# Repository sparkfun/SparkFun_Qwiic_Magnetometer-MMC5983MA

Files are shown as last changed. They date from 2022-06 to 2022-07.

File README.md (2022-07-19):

# SparkFun_Qwiic_Magnetometer-MMC5983MA
========================================

SparkFun Qwiic Magnetometer-MMC5983MA (https://www.sparkfun.com/products/19921)

[*SparkFun Qwiic Magnetometer-MMC5983MA (19921)*](https://www.sparkfun.com/products/19921)

The SparkFun Qwiic Micro MMC5983MA Magnetometer takes the highly sensitive triple-axis magnetometer by MEMSIC. We've attached the magetometer IC onto an incredibly small Qwiic board form factor that we like to call, Qwiic Micro! The MMC5983MA is capable of sensing down to 0.4mG enabling a heading accuracy of ±0.5°. Output rates of 1000Hz, ±8G FSR, and 18-bit resolution make the MMC5983MA a phenomenal magnetic sensor for electronic compass applications.

Saturation is a problem for all mag sensors. The MMC5983MA has built-in degaussing circuitry to clear any residual magnetization.

We've got a feature complete Arduino library supporting I<sup>2</sup>C and SPI. Just search "SparkFun MMA5983MA" in the library manager and get measuring within minutes.

Repository Contents
-------------------

* **/Documentation** - Data sheets, additional product information
* **/Firmware** - Example code 
* **/Hardware** - Eagle design files (.brd, .sch)
* **/Libraries** - Libraries for use with the <PRODUCT NAME>

Documentation
--------------
* **[Library](https://github.com/sparkfun/SparkFun_MMC5983MA_Magnetometer_Arduino_Library)** - Arduino library for the SparkFun_Qwiic_Magnetometer-MMC5983MA.
* **[Hookup Guide](https://learn.sparkfun.com/tutorials/qwiic-micro-magnetometer---mmc5983ma-hookup-guide)** - Basic hookup guide for the SparkFun Qwiic Magnetometer-MMC5983MA.

License Information
-------------------

This product is _**open source**_! 

Please review the LICENSE.md file for license information. 

If you have any questions or concerns on licensing, please contact technical support on our [SparkFun forums](https://forum.sparkfun.com/viewforum.php?f=152).

Distributed as-is; no warranty is given.

- Your friends at SparkFun.

_<COLLABORATION CREDIT>_

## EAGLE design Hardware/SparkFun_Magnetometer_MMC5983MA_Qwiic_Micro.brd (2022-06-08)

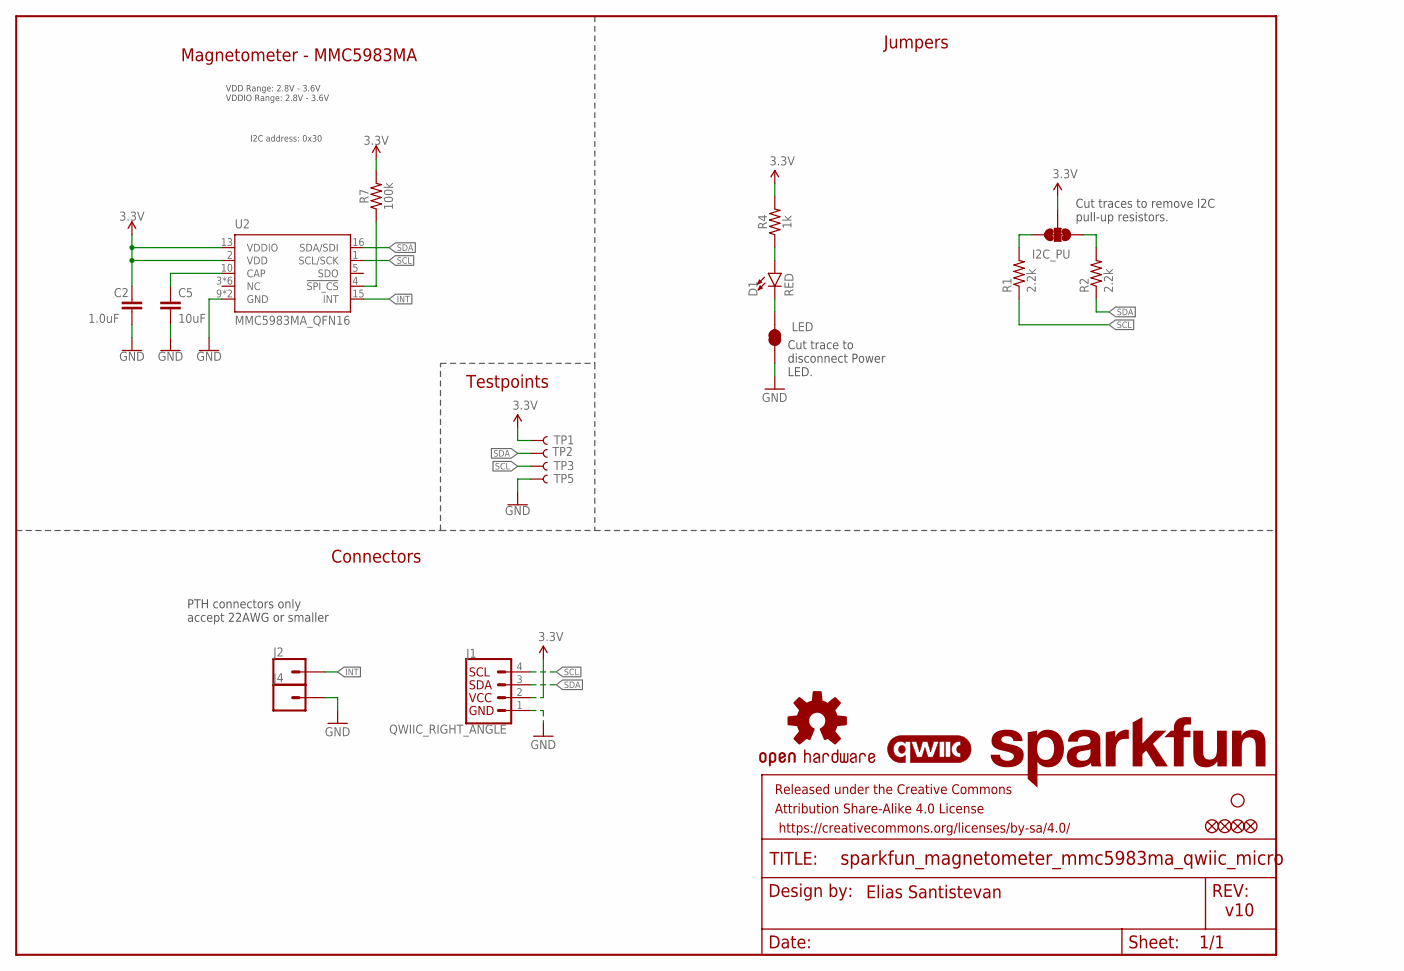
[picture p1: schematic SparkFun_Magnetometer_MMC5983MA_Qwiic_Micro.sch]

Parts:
C2: 1.0uF; 0402-TIGHT
C5: 10uF; 0402-TIGHT
D1: RED; LED-0402
FD1, FD2: FIDUCIALUFIDUCIAL; FIDUCIAL-MICRO
FID1, FID2: FIDUCIALUFIDUCIAL; FIDUCIAL-MICRO
FRAME1: FRAME-LETTER; CREATIVE_COMMONS
I2C_PU: S_MODE; SMT-JUMPER_3_2-NC_TRACE_SILK
J1: QWIIC_RIGHT_ANGLE; JST04_1MM_RA
J2, J4: CONN_01_1MM; 1X01_1MM_NO_SILK
LED: JUMPER-SMT_2_NC_TRACE_SILK; SMT-JUMPER_2_NC_TRACE_SILK
LOGO1: QWIIC_LOGO_4MM; QWIIC_4MM
LOGO2: OSHW-LOGOMINI; OSHW-LOGO-MINI
LOGO3: SFE_LOGO_NAMEBLANK; BLANK
R1, R2: 2.2k; 0402-TIGHT
R4: 1k; 0402-TIGHT
R7: 100k; 0402-TIGHT
STANDOFF3: STAND-OFFTIGHT; STAND-OFF-TIGHT
TP1, TP2, TP3, TP5: TEST-POINT3; PAD.03X.03
U2: MMC5983MA_QFN16; LGA-16-3X3MM-4X4PINS

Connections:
3.3V: C2.1, I2C_PU.2, J1.2, R4.2, R7.2, TP1.1, U2.2 (VDD), U2.13 (VDDIO)
!MAG_CS!: R7.1, U2.4 (!SPI_CS!)
CAP: C5.1, U2.10 (CAP)
GND: C2.2, C5.2, J1.1, J4.1, LED.1, TP5.1, U2.9 (GND), U2.11 (GND)
INT: J2.1, U2.15 (INT)
unnamed: D1.A, R4.1
unnamed: D1.C, LED.2
unnamed: I2C_PU.1, R1.2
unnamed: I2C_PU.3, R2.2
SCL: J1.4, R1.1, TP3.1, U2.1 (SCL/SCK)
SDA: J1.3, R2.1, TP2.1, U2.16 (SDA/SDI)

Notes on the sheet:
Cut traces to remove I2C pull-up resistors.
v10
Jumpers
Cut trace to disconnect Power LED.
Connectors
Elias Santistevan
Testpoints
VDD Range: 2.8V - 3.6V VDDIO Range: 2.8V - 3.6V
Magnetometer - MMC5983MA
I2C address: 0x30
PTH connectors only accept 22AWG or smaller

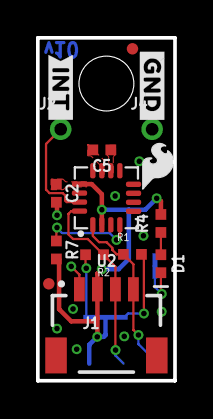
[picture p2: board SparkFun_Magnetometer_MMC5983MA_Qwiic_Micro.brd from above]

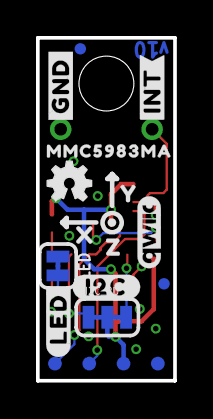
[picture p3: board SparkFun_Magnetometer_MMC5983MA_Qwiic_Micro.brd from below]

Board: 2 copper layers, 7.6 x 19.1 mm, 37 parts (18 on the bottom side), 11 nets.

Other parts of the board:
U$1: #INT#20
U$2: MMC5983MA331
U$3: #I2C#4
U$4, U$6: #GND#4
U$5: #INT#21
U$8: X2114
U$9: Y2115
U$10: Z2116
U$11: #LED#5
U$29: SFE_LOGO_FLAME_.1

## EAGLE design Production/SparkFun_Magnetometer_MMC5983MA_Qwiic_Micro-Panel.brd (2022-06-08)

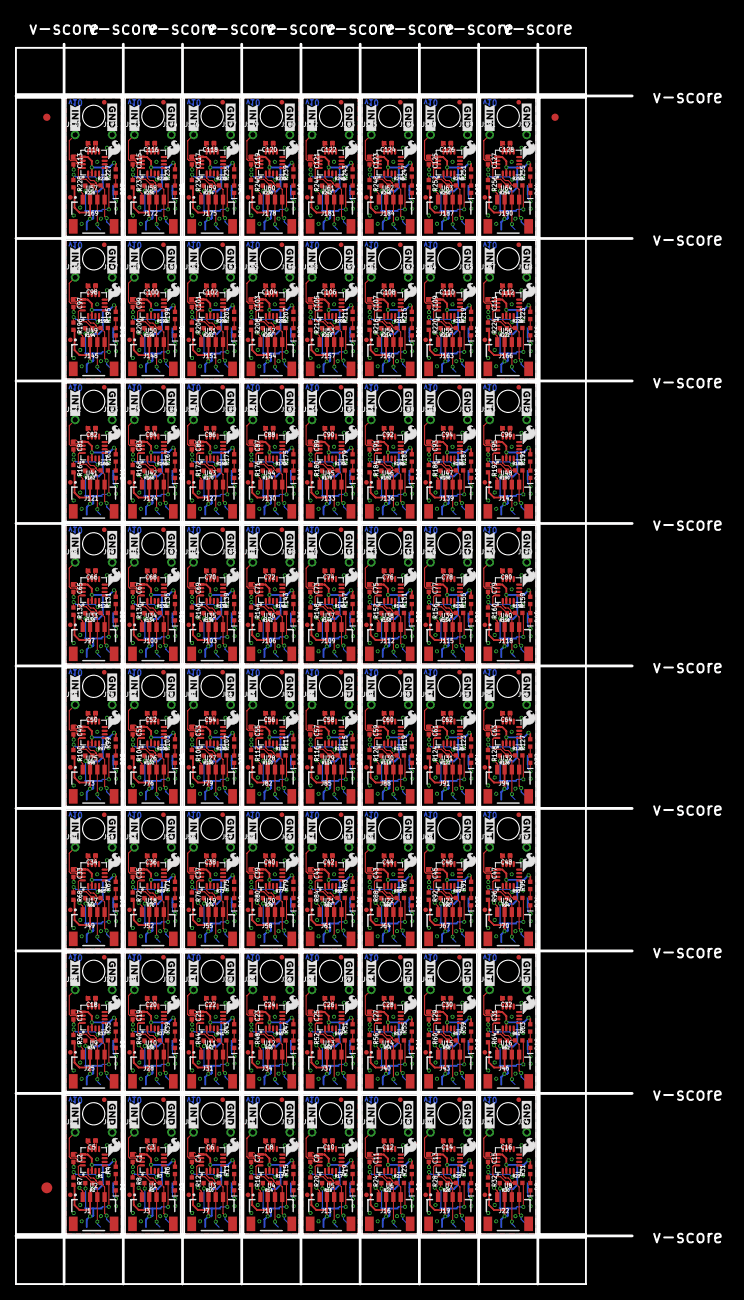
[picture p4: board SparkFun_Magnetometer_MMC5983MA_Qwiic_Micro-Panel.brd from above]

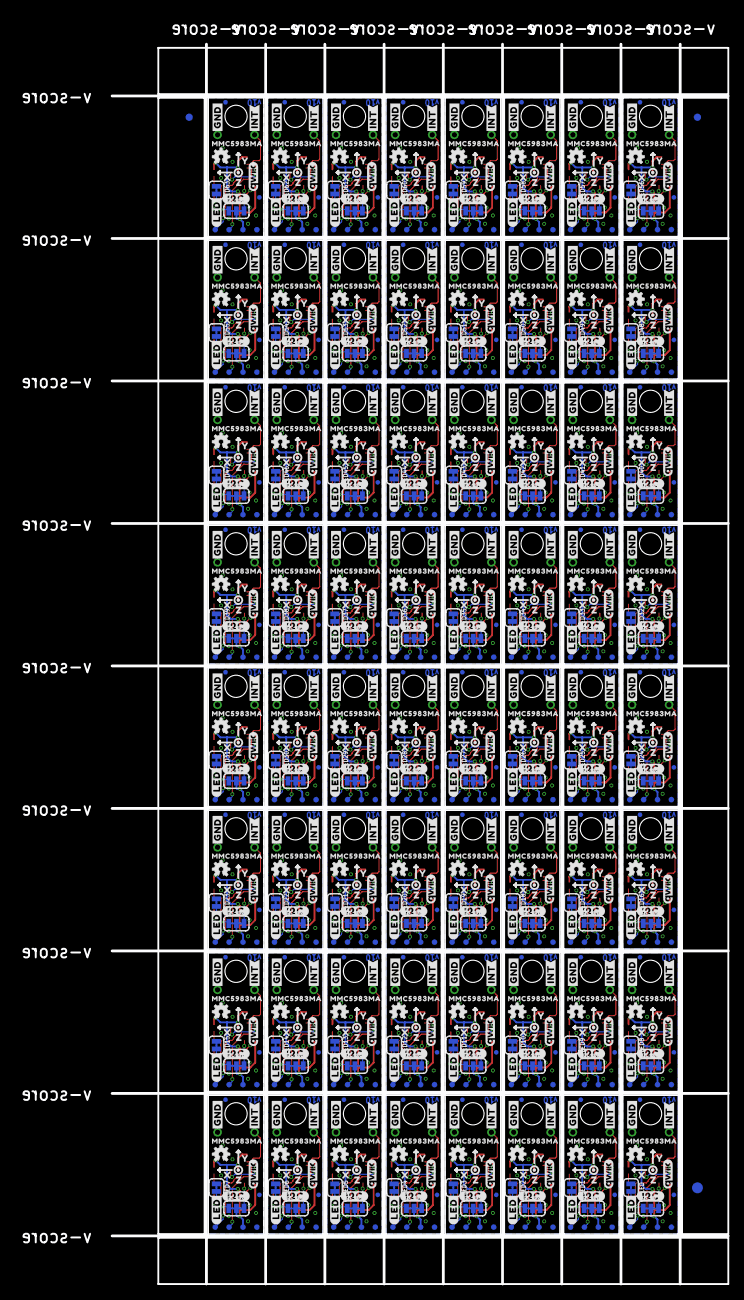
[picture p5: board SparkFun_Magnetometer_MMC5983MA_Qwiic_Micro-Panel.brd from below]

Board: 2 copper layers, 84.6 x 170.2 mm, 2374 parts (1155 on the bottom side), 704 nets.

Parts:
C1, C2, C4, C7, C9, C11, C13, C15, C17, C19, C21, C23, C25, C27, C29, C31, C33, C35, C37, C39, C41, C43, C45, C47, C49, C51, C53, C55, C57, C59, C61, C63, C65, C67, C69, C71, C73, C75, C77, C79, C81, C83, C85, C87, C89, C91, C93, C95, C97, C99, C101, C103, C105, C107, C109, C111, C113, C115, C117, C119, C121, C123, C125, C127: 1.0uF; 0402-TIGHT
C3, C5, C6, C8, C10, C12, C14, C16, C18, C20, C22, C24, C26, C28, C30, C32, C34, C36, C38, C40, C42, C44, C46, C48, C50, C52, C54, C56, C58, C60, C62, C64, C66, C68, C70, C72, C74, C76, C78, C80, C82, C84, C86, C88, C90, C92, C94, C96, C98, C100, C102, C104, C106, C108, C110, C112, C114, C116, C118, C120, C122, C124, C126, C128: 10uF; 0402-TIGHT
D1, D2, D3, D4, D5, D6, D7, D8, D9, D10, D11, D12, D13, D14, D15, D16, D17, D18, D19, D20, D21, D22, D23, D24, D25, D26, D27, D28, D29, D30, D31, D32, D33, D34, D35, D36, D37, D38, D39, D40, D41, D42, D43, D44, D45, D46, D47, D48, D49, D50, D51, D52, D53, D54, D55, D56, D57, D58, D59, D60, D61, D62, D63, D64: RED; LED-0402
E$1, E$2, E$3, E$4: FIDUCIAL-1X2
E$5, E$6: FIDUCIAL-1.5X3
FD1, FD2, FD3, FD4, FD5, FD6, FD7, FD8, FD9, FD10, FD11, FD12, FD13, FD14, FD15, FD16, FD17, FD18, FD19, FD20, FD21, FD22, FD23, FD24, FD25, FD26, FD27, FD28, FD29, FD30, FD31, FD32, FD33, FD34, FD35, FD36, FD37, FD38, FD39, FD40, FD41, FD42, FD43, FD44, FD45, FD46, FD47, FD48, FD49, FD50, FD51, FD52, FD53, FD54, FD55, FD56, FD57, FD58, FD59, FD60, FD61, FD62, FD63, FD64, FD65, FD66, FD67, FD68, FD69, FD70, FD71, FD72, FD73, FD74, FD75, FD76, FD77, FD78, FD79, FD80, FD81, FD82, FD83, FD84, FD85, FD86, FD87, FD88, FD89, FD90, FD91, FD92, FD93, FD94, FD95, FD96, FD97, FD98, FD99, FD100, FD101, FD102, FD103, FD104, FD105, FD106, FD107, FD108, FD109, FD110, FD111, FD112, FD113, FD114, FD115, FD116, FD117, FD118, FD119, FD120, FD121, FD122, FD123, FD124, FD125, FD126, FD127, FD128: FIDUCIALUFIDUCIAL; FIDUCIAL-MICRO
FID1, FID2, FID3, FID4, FID5, FID6, FID7, FID8, FID9, FID10, FID11, FID12, FID13, FID14, FID15, FID16, FID17, FID18, FID19, FID20, FID21, FID22, FID23, FID24, FID25, FID26, FID27, FID28, FID29, FID30, FID31, FID32, FID33, FID34, FID35, FID36, FID37, FID38, FID39, FID40, FID41, FID42, FID43, FID44, FID45, FID46, FID47, FID48, FID49, FID50, FID51, FID52, FID53, FID54, FID55, FID56, FID57, FID58, FID59, FID60, FID61, FID62, FID63, FID64, FID65, FID66, FID67, FID68, FID69, FID70, FID71, FID72, FID73, FID74, FID75, FID76, FID77, FID78, FID79, FID80, FID81, FID82, FID83, FID84, FID85, FID86, FID87, FID88, FID89, FID90, FID91, FID92, FID93, FID94, FID95, FID96, FID97, FID98, FID99, FID100, FID101, FID102, FID103, FID104, FID105, FID106, FID107, FID108, FID109, FID110, FID111, FID112, FID113, FID114, FID115, FID116, FID117, FID118, FID119, FID120, FID121, FID122, FID123, FID124, FID125, FID126, FID127, FID128: FIDUCIALUFIDUCIAL; FIDUCIAL-MICRO
FRAME1, FRAME2, FRAME3, FRAME4, FRAME5, FRAME6, FRAME7, FRAME8, FRAME9, FRAME10, FRAME11, FRAME12, FRAME13, FRAME14, FRAME15, FRAME16, FRAME17, FRAME18, FRAME19, FRAME20, FRAME21, FRAME22, FRAME23, FRAME24, FRAME25, FRAME26, FRAME27, FRAME28, FRAME29, FRAME30, FRAME31, FRAME32, FRAME33, FRAME34, FRAME35, FRAME36, FRAME37, FRAME38, FRAME39, FRAME40, FRAME41, FRAME42, FRAME43, FRAME44, FRAME45, FRAME46, FRAME47, FRAME48, FRAME49, FRAME50, FRAME51, FRAME52, FRAME53, FRAME54, FRAME55, FRAME56, FRAME57, FRAME58, FRAME59, FRAME60, FRAME61, FRAME62, FRAME63, FRAME64: FRAME-LETTER; CREATIVE_COMMONS
I2C_PU, I2C_PU1, I2C_PU2, I2C_PU3, I2C_PU4, I2C_PU5, I2C_PU6, I2C_PU7, I2C_PU8, I2C_PU9, I2C_PU10, I2C_PU11, I2C_PU12, I2C_PU13, I2C_PU14, I2C_PU15, I2C_PU16, I2C_PU17, I2C_PU18, I2C_PU19, I2C_PU20, I2C_PU21, I2C_PU22, I2C_PU23, I2C_PU24, I2C_PU25, I2C_PU26, I2C_PU27, I2C_PU28, I2C_PU29, I2C_PU30, I2C_PU31, I2C_PU32, I2C_PU33, I2C_PU34, I2C_PU35, I2C_PU36, I2C_PU37, I2C_PU38, I2C_PU39, I2C_PU40, I2C_PU41, I2C_PU42, I2C_PU43, I2C_PU44, I2C_PU45, I2C_PU46, I2C_PU47, I2C_PU48, I2C_PU49, I2C_PU50, I2C_PU51, I2C_PU52, I2C_PU53, I2C_PU54, I2C_PU55, I2C_PU56, I2C_PU57, I2C_PU58, I2C_PU59, I2C_PU60, I2C_PU61, I2C_PU62, I2C_PU63: S_MODE; SMT-JUMPER_3_2-NC_TRACE_SILK
J1, J3, J7, J10, J13, J16, J19, J22, J25, J28, J31, J34, J37, J40, J43, J46, J49, J52, J55, J58, J61, J64, J67, J70, J73, J76, J79, J82, J85, J88, J91, J94, J97, J100, J103, J106, J109, J112, J115, J118, J121, J124, J127, J130, J133, J136, J139, J142, J145, J148, J151, J154, J157, J160, J163, J166, J169, J172, J175, J178, J181, J184, J187, J190: QWIIC_RIGHT_ANGLE; JST04_1MM_RA
J2, J4, J5, J6, J8, J9, J11, J12, J14, J15, J17, J18, J20, J21, J23, J24, J26, J27, J29, J30, J32, J33, J35, J36, J38, J39, J41, J42, J44, J45, J47, J48, J50, J51, J53, J54, J56, J57, J59, J60, J62, J63, J65, J66, J68, J69, J71, J72, J74, J75, J77, J78, J80, J81, J83, J84, J86, J87, J89, J90, J92, J93, J95, J96, J98, J99, J101, J102, J104, J105, J107, J108, J110, J111, J113, J114, J116, J117, J119, J120, J122, J123, J125, J126, J128, J129, J131, J132, J134, J135, J137, J138, J140, J141, J143, J144, J146, J147, J149, J150, J152, J153, J155, J156, J158, J159, J161, J162, J164, J165, J167, J168, J170, J171, J173, J174, J176, J177, J179, J180, J182, J183, J185, J186, J188, J189, J191, J192: 1X01_1MM_NO_SILK
LED, LED1, LED2, LED3, LED4, LED5, LED6, LED7, LED8, LED9, LED10, LED11, LED12, LED13, LED14, LED15, LED16, LED17, LED18, LED19, LED20, LED21, LED22, LED23, LED24, LED25, LED26, LED27, LED28, LED29, LED30, LED31, LED32, LED33, LED34, LED35, LED36, LED37, LED38, LED39, LED40, LED41, LED42, LED43, LED44, LED45, LED46, LED47, LED48, LED49, LED50, LED51, LED52, LED53, LED54, LED55, LED56, LED57, LED58, LED59, LED60, LED61, LED62, LED63: JUMPER-SMT_2_NC_TRACE_SILK; SMT-JUMPER_2_NC_TRACE_SILK
LOGO1, LOGO5, LOGO8, LOGO11, LOGO14, LOGO17, LOGO20, LOGO23, LOGO26, LOGO29, LOGO32, LOGO35, LOGO38, LOGO41, LOGO44, LOGO47, LOGO50, LOGO53, LOGO56, LOGO59, LOGO62, LOGO65, LOGO68, LOGO71, LOGO74, LOGO77, LOGO80, LOGO83, LOGO86, LOGO89, LOGO92, LOGO95, LOGO98, LOGO101, LOGO104, LOGO107, LOGO110, LOGO113, LOGO116, LOGO119, LOGO122, LOGO125, LOGO128, LOGO131, LOGO134, LOGO137, LOGO140, LOGO143, LOGO146, LOGO149, LOGO152, LOGO155, LOGO158, LOGO161, LOGO164, LOGO167, LOGO170, LOGO173, LOGO176, LOGO179, LOGO182, LOGO185, LOGO188, LOGO191: QWIIC_LOGO_4MM; QWIIC_4MM
LOGO2, LOGO4, LOGO7, LOGO10, LOGO13, LOGO16, LOGO19, LOGO22, LOGO25, LOGO28, LOGO31, LOGO34, LOGO37, LOGO40, LOGO43, LOGO46, LOGO49, LOGO52, LOGO55, LOGO58, LOGO61, LOGO64, LOGO67, LOGO70, LOGO73, LOGO76, LOGO79, LOGO82, LOGO85, LOGO88, LOGO91, LOGO94, LOGO97, LOGO100, LOGO103, LOGO106, LOGO109, LOGO112, LOGO115, LOGO118, LOGO121, LOGO124, LOGO127, LOGO130, LOGO133, LOGO136, LOGO139, LOGO142, LOGO145, LOGO148, LOGO151, LOGO154, LOGO157, LOGO160, LOGO163, LOGO166, LOGO169, LOGO172, LOGO175, LOGO178, LOGO181, LOGO184, LOGO187, LOGO190: OSHW-LOGOMINI; OSHW-LOGO-MINI
LOGO3, LOGO6, LOGO9, LOGO12, LOGO15, LOGO18, LOGO21, LOGO24, LOGO27, LOGO30, LOGO33, LOGO36, LOGO39, LOGO42, LOGO45, LOGO48, LOGO51, LOGO54, LOGO57, LOGO60, LOGO63, LOGO66, LOGO69, LOGO72, LOGO75, LOGO78, LOGO81, LOGO84, LOGO87, LOGO90, LOGO93, LOGO96, LOGO99, LOGO102, LOGO105, LOGO108, LOGO111, LOGO114, LOGO117, LOGO120, LOGO123, LOGO126, LOGO129, LOGO132, LOGO135, LOGO138, LOGO141, LOGO144, LOGO147, LOGO150, LOGO153, LOGO156, LOGO159, LOGO162, LOGO165, LOGO168, LOGO171, LOGO174, LOGO177, LOGO180, LOGO183, LOGO186, LOGO189, LOGO192: SFE_LOGO_NAMEBLANK; BLANK
R1, R2, R3, R5, R9, R10, R13, R14, R17, R18, R21, R22, R25, R26, R29, R30, R33, R34, R37, R38, R41, R42, R45, R46, R49, R50, R53, R54, R57, R58, R61, R62, R65, R66, R69, R70, R73, R74, R77, R78, R81, R82, R85, R86, R89, R90, R93, R94, R97, R98, R101, R102, R105, R106, R109, R110, R113, R114, R117, R118, R121, R122, R125, R126, R129, R130, R133, R134, R137, R138, R141, R142, R145, R146, R149, R150, R153, R154, R157, R158, R161, R162, R165, R166, R169, R170, R173, R174, R177, R178, R181, R182, R185, R186, R189, R190, R193, R194, R197, R198, R201, R202, R205, R206, R209, R210, R213, R214, R217, R218, R221, R222, R225, R226, R229, R230, R233, R234, R237, R238, R241, R242, R245, R246, R249, R250, R253, R254: 2.2k; 0402-TIGHT
R4, R6, R11, R15, R19, R23, R27, R31, R35, R39, R43, R47, R51, R55, R59, R63, R67, R71, R75, R79, R83, R87, R91, R95, R99, R103, R107, R111, R115, R119, R123, R127, R131, R135, R139, R143, R147, R151, R155, R159, R163, R167, R171, R175, R179, R183, R187, R191, R195, R199, R203, R207, R211, R215, R219, R223, R227, R231, R235, R239, R243, R247, R251, R255: 1k; 0402-TIGHT
R7, R8, R12, R16, R20, R24, R28, R32, R36, R40, R44, R48, R52, R56, R60, R64, R68, R72, R76, R80, R84, R88, R92, R96, R100, R104, R108, R112, R116, R120, R124, R128, R132, R136, R140, R144, R148, R152, R156, R160, R164, R168, R172, R176, R180, R184, R188, R192, R196, R200, R204, R208, R212, R216, R220, R224, R228, R232, R236, R240, R244, R248, R252, R256: 100k; 0402-TIGHT
STANDOFF1, STANDOFF2, STANDOFF3, STANDOFF4, STANDOFF5, STANDOFF6, STANDOFF7, STANDOFF8, STANDOFF9, STANDOFF10, STANDOFF11, STANDOFF12, STANDOFF13, STANDOFF14, STANDOFF15, STANDOFF16, STANDOFF17, STANDOFF18, STANDOFF19, STANDOFF20, STANDOFF21, STANDOFF22, STANDOFF23, STANDOFF24, STANDOFF25, STANDOFF26, STANDOFF27, STANDOFF28, STANDOFF29, STANDOFF30, STANDOFF31, STANDOFF32, STANDOFF33, STANDOFF34, STANDOFF35, STANDOFF36, STANDOFF37, STANDOFF38, STANDOFF39, STANDOFF40, STANDOFF41, STANDOFF42, STANDOFF43, STANDOFF44, STANDOFF45, STANDOFF46, STANDOFF47, STANDOFF48, STANDOFF49, STANDOFF50, STANDOFF51, STANDOFF52, STANDOFF53, STANDOFF54, STANDOFF55, STANDOFF56, STANDOFF57, STANDOFF58, STANDOFF59, STANDOFF60, STANDOFF61, STANDOFF62, STANDOFF63, STANDOFF64: STAND-OFFTIGHT; STAND-OFF-TIGHT
TP1, TP2, TP3, TP4, TP5, TP6, TP7, TP8, TP9, TP10, TP11, TP12, TP13, TP14, TP15, TP16, TP17, TP18, TP19, TP20, TP21, TP22, TP23, TP24, TP25, TP26, TP27, TP28, TP29, TP30, TP31, TP32, TP33, TP34, TP35, TP36, TP37, TP38, TP39, TP40, TP41, TP42, TP43, TP44, TP45, TP46, TP47, TP48, TP49, TP50, TP51, TP52, TP53, TP54, TP55, TP56, TP57, TP58, TP59, TP60, TP61, TP62, TP63, TP64, TP65, TP66, TP67, TP68, TP69, TP70, TP71, TP72, TP73, TP74, TP75, TP76, TP77, TP78, TP79, TP80, TP81, TP82, TP83, TP84, TP85, TP86, TP87, TP88, TP89, TP90, TP91, TP92, TP93, TP94, TP95, TP96, TP97, TP98, TP99, TP100, TP101, TP102, TP103, TP104, TP105, TP106, TP107, TP108, TP109, TP110, TP111, TP112, TP113, TP114, TP115, TP116, TP117, TP118, TP119, TP120, TP121, TP122, TP123, TP124, TP125, TP126, TP127, TP128, TP129, TP130, TP131, TP132, TP133, TP134, TP135, TP136, TP137, TP138, TP139, TP140, TP141, TP142, TP143, TP144, TP145, TP146, TP147, TP148, TP149, TP150, TP151, TP152, TP153, TP154, TP155, TP156, TP157, TP158, TP159, TP160, TP161, TP162, TP163, TP164, TP165, TP166, TP167, TP168, TP169, TP170, TP171, TP172, TP173, TP174, TP175, TP176, TP177, TP178, TP179, TP180, TP181, TP182, TP183, TP184, TP185, TP186, TP187, TP188, TP189, TP190, TP191, TP192, TP193, TP194, TP195, TP196, TP197, TP198, TP199, TP200, TP201, TP202, TP203, TP204, TP205, TP206, TP207, TP208, TP209, TP210, TP211, TP212, TP213, TP214, TP215, TP216, TP217, TP218, TP219, TP220, TP221, TP222, TP223, TP224, TP225, TP226, TP227, TP228, TP229, TP230, TP231, TP232, TP233, TP234, TP235, TP236, TP237, TP238, TP239, TP240, TP241, TP242, TP243, TP244, TP245, TP246, TP247, TP248, TP249, TP250, TP251, TP252, TP253, TP254, TP255, TP256: TEST-POINT3; PAD.03X.03
U1, U2, U3, U4, U5, U6, U7, U8, U9, U10, U11, U12, U13, U14, U15, U16, U17, U18, U19, U20, U21, U22, U23, U24, U25, U26, U27, U28, U29, U30, U31, U32, U33, U34, U35, U36, U37, U38, U39, U40, U41, U42, U43, U44, U45, U46, U47, U48, U49, U50, U51, U52, U53, U54, U55, U56, U57, U58, U59, U60, U61, U62, U63, U64: MMC5983MA_QFN16; LGA-16-3X3MM-4X4PINS
U$1, U$18, U$30, U$41, U$52, U$63, U$74, U$85, U$96, U$107, U$118, U$129, U$140, U$151, U$162, U$173, U$184, U$195, U$206, U$217, U$228, U$239, U$250, U$261, U$272, U$283, U$294, U$305, U$316, U$327, U$338, U$349, U$360, U$371, U$382, U$393, U$404, U$415, U$426, U$437, U$448, U$459, U$470, U$481, U$492, U$503, U$514, U$525, U$536, U$547, U$558, U$569, U$580, U$591, U$602, U$613, U$624, U$635, U$646, U$657, U$668, U$679, U$690, U$701: #INT#20
U$2, U$15, U$26, U$38, U$49, U$60, U$71, U$82, U$93, U$104, U$115, U$126, U$137, U$148, U$159, U$170, U$181, U$192, U$203, U$214, U$225, U$236, U$247, U$258, U$269, U$280, U$291, U$302, U$313, U$324, U$335, U$346, U$357, U$368, U$379, U$390, U$401, U$412, U$423, U$434, U$445, U$456, U$467, U$478, U$489, U$500, U$511, U$522, U$533, U$544, U$555, U$566, U$577, U$588, U$599, U$610, U$621, U$632, U$643, U$654, U$665, U$676, U$687, U$698: MMC5983MA331
U$3, U$16, U$27, U$39, U$50, U$61, U$72, U$83, U$94, U$105, U$116, U$127, U$138, U$149, U$160, U$171, U$182, U$193, U$204, U$215, U$226, U$237, U$248, U$259, U$270, U$281, U$292, U$303, U$314, U$325, U$336, U$347, U$358, U$369, U$380, U$391, U$402, U$413, U$424, U$435, U$446, U$457, U$468, U$479, U$490, U$501, U$512, U$523, U$534, U$545, U$556, U$567, U$578, U$589, U$600, U$611, U$622, U$633, U$644, U$655, U$666, U$677, U$688, U$699: #I2C#4
U$4, U$6, U$19, U$21, U$31, U$33, U$42, U$44, U$53, U$55, U$64, U$66, U$75, U$77, U$86, U$88, U$97, U$99, U$108, U$110, U$119, U$121, U$130, U$132, U$141, U$143, U$152, U$154, U$163, U$165, U$174, U$176, U$185, U$187, U$196, U$198, U$207, U$209, U$218, U$220, U$229, U$231, U$240, U$242, U$251, U$253, U$262, U$264, U$273, U$275, U$284, U$286, U$295, U$297, U$306, U$308, U$317, U$319, U$328, U$330, U$339, U$341, U$350, U$352, U$361, U$363, U$372, U$374, U$383, U$385, U$394, U$396, U$405, U$407, U$416, U$418, U$427, U$429, U$438, U$440, U$449, U$451, U$460, U$462, U$471, U$473, U$482, U$484, U$493, U$495, U$504, U$506, U$515, U$517, U$526, U$528, U$537, U$539, U$548, U$550, U$559, U$561, U$570, U$572, U$581, U$583, U$592, U$594, U$603, U$605, U$614, U$616, U$625, U$627, U$636, U$638, U$647, U$649, U$658, U$660, U$669, U$671, U$680, U$682, U$691, U$693, U$702, U$704: #GND#4
U$5, U$20, U$32, U$43, U$54, U$65, U$76, U$87, U$98, U$109, U$120, U$131, U$142, U$153, U$164, U$175, U$186, U$197, U$208, U$219, U$230, U$241, U$252, U$263, U$274, U$285, U$296, U$307, U$318, U$329, U$340, U$351, U$362, U$373, U$384, U$395, U$406, U$417, U$428, U$439, U$450, U$461, U$472, U$483, U$494, U$505, U$516, U$527, U$538, U$549, U$560, U$571, U$582, U$593, U$604, U$615, U$626, U$637, U$648, U$659, U$670, U$681, U$692, U$703: #INT#21
U$7, U$22, U$29, U$34, U$45, U$56, U$67, U$78, U$89, U$100, U$111, U$122, U$133, U$144, U$155, U$166, U$177, U$188, U$199, U$210, U$221, U$232, U$243, U$254, U$265, U$276, U$287, U$298, U$309, U$320, U$331, U$342, U$353, U$364, U$375, U$386, U$397, U$408, U$419, U$430, U$441, U$452, U$463, U$474, U$485, U$496, U$507, U$518, U$529, U$540, U$551, U$562, U$573, U$584, U$595, U$606, U$617, U$628, U$639, U$650, U$661, U$672, U$683, U$694: SFE_LOGO_FLAME_.1
U$8, U$12, U$23, U$35, U$46, U$57, U$68, U$79, U$90, U$101, U$112, U$123, U$134, U$145, U$156, U$167, U$178, U$189, U$200, U$211, U$222, U$233, U$244, U$255, U$266, U$277, U$288, U$299, U$310, U$321, U$332, U$343, U$354, U$365, U$376, U$387, U$398, U$409, U$420, U$431, U$442, U$453, U$464, U$475, U$486, U$497, U$508, U$519, U$530, U$541, U$552, U$563, U$574, U$585, U$596, U$607, U$618, U$629, U$640, U$651, U$662, U$673, U$684, U$695: X2114
U$9, U$13, U$24, U$36, U$47, U$58, U$69, U$80, U$91, U$102, U$113, U$124, U$135, U$146, U$157, U$168, U$179, U$190, U$201, U$212, U$223, U$234, U$245, U$256, U$267, U$278, U$289, U$300, U$311, U$322, U$333, U$344, U$355, U$366, U$377, U$388, U$399, U$410, U$421, U$432, U$443, U$454, U$465, U$476, U$487, U$498, U$509, U$520, U$531, U$542, U$553, U$564, U$575, U$586, U$597, U$608, U$619, U$630, U$641, U$652, U$663, U$674, U$685, U$696: Y2115
U$10, U$14, U$25, U$37, U$48, U$59, U$70, U$81, U$92, U$103, U$114, U$125, U$136, U$147, U$158, U$169, U$180, U$191, U$202, U$213, U$224, U$235, U$246, U$257, U$268, U$279, U$290, U$301, U$312, U$323, U$334, U$345, U$356, U$367, U$378, U$389, U$400, U$411, U$422, U$433, U$444, U$455, U$466, U$477, U$488, U$499, U$510, U$521, U$532, U$543, U$554, U$565, U$576, U$587, U$598, U$609, U$620, U$631, U$642, U$653, U$664, U$675, U$686, U$697: Z2116
U$11, U$17, U$28, U$40, U$51, U$62, U$73, U$84, U$95, U$106, U$117, U$128, U$139, U$150, U$161, U$172, U$183, U$194, U$205, U$216, U$227, U$238, U$249, U$260, U$271, U$282, U$293, U$304, U$315, U$326, U$337, U$348, U$359, U$370, U$381, U$392, U$403, U$414, U$425, U$436, U$447, U$458, U$469, U$480, U$491, U$502, U$513, U$524, U$535, U$546, U$557, U$568, U$579, U$590, U$601, U$612, U$623, U$634, U$645, U$656, U$667, U$678, U$689, U$700: #LED#5

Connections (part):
3.3V: C2.1, I2C_PU.2, J1.2, R4.2, R7.2, TP1.1, U2.2, U2.13
3.3V1: C1.1, I2C_PU1.2, J3.2, R6.2, R8.2, TP4.1, U1.2, U1.13
3.3V2: C4.1, I2C_PU2.2, J7.2, R11.2, R12.2, TP9.1, U3.2, U3.13
3.3V3: C7.1, I2C_PU3.2, J10.2, R15.2, R16.2, TP13.1, U4.2, U4.13
3.3V4: C9.1, I2C_PU4.2, J13.2, R19.2, R20.2, TP17.1, U5.2, U5.13
3.3V5: C11.1, I2C_PU5.2, J16.2, R23.2, R24.2, TP21.1, U6.2, U6.13
3.3V6: C13.1, I2C_PU6.2, J19.2, R27.2, R28.2, TP25.1, U7.2, U7.13
3.3V7: C15.1, I2C_PU7.2, J22.2, R31.2, R32.2, TP29.1, U8.2, U8.13
3.3V8: C17.1, I2C_PU8.2, J25.2, R35.2, R36.2, TP33.1, U9.2, U9.13
3.3V9: C19.1, I2C_PU9.2, J28.2, R39.2, R40.2, TP37.1, U10.2, U10.13
3.3V10: C21.1, I2C_PU10.2, J31.2, R43.2, R44.2, TP41.1, U11.2, U11.13
3.3V11: C23.1, I2C_PU11.2, J34.2, R47.2, R48.2, TP45.1, U12.2, U12.13
3.3V12: C25.1, I2C_PU12.2, J37.2, R51.2, R52.2, TP49.1, U13.2, U13.13
3.3V13: C27.1, I2C_PU13.2, J40.2, R55.2, R56.2, TP53.1, U14.2, U14.13
3.3V14: C29.1, I2C_PU14.2, J43.2, R59.2, R60.2, TP57.1, U15.2, U15.13
3.3V15: C31.1, I2C_PU15.2, J46.2, R63.2, R64.2, TP61.1, U16.2, U16.13
3.3V16: C33.1, I2C_PU16.2, J49.2, R67.2, R68.2, TP65.1, U17.2, U17.13
3.3V17: C35.1, I2C_PU17.2, J52.2, R71.2, R72.2, TP69.1, U18.2, U18.13
3.3V18: C37.1, I2C_PU18.2, J55.2, R75.2, R76.2, TP73.1, U19.2, U19.13
3.3V19: C39.1, I2C_PU19.2, J58.2, R79.2, R80.2, TP77.1, U20.2, U20.13
3.3V20: C41.1, I2C_PU20.2, J61.2, R83.2, R84.2, TP81.1, U21.2, U21.13
3.3V21: C43.1, I2C_PU21.2, J64.2, R87.2, R88.2, TP85.1, U22.2, U22.13
3.3V22: C45.1, I2C_PU22.2, J67.2, R91.2, R92.2, TP89.1, U23.2, U23.13
3.3V23: C47.1, I2C_PU23.2, J70.2, R95.2, R96.2, TP93.1, U24.2, U24.13
3.3V24: C49.1, I2C_PU24.2, J73.2, R99.2, R100.2, TP97.1, U25.2, U25.13
3.3V25: C51.1, I2C_PU25.2, J76.2, R103.2, R104.2, TP101.1, U26.2, U26.13
3.3V26: C53.1, I2C_PU26.2, J79.2, R107.2, R108.2, TP105.1, U27.2, U27.13
3.3V27: C55.1, I2C_PU27.2, J82.2, R111.2, R112.2, TP109.1, U28.2, U28.13
3.3V28: C57.1, I2C_PU28.2, J85.2, R115.2, R116.2, TP113.1, U29.2, U29.13
3.3V29: C59.1, I2C_PU29.2, J88.2, R119.2, R120.2, TP117.1, U30.2, U30.13
3.3V30: C61.1, I2C_PU30.2, J91.2, R123.2, R124.2, TP121.1, U31.2, U31.13
3.3V31: C63.1, I2C_PU31.2, J94.2, R127.2, R128.2, TP125.1, U32.2, U32.13
3.3V32: C65.1, I2C_PU32.2, J97.2, R131.2, R132.2, TP129.1, U33.2, U33.13
3.3V33: C67.1, I2C_PU33.2, J100.2, R135.2, R136.2, TP133.1, U34.2, U34.13
3.3V34: C69.1, I2C_PU34.2, J103.2, R139.2, R140.2, TP137.1, U35.2, U35.13
3.3V35: C71.1, I2C_PU35.2, J106.2, R143.2, R144.2, TP141.1, U36.2, U36.13
3.3V36: C73.1, I2C_PU36.2, J109.2, R147.2, R148.2, TP145.1, U37.2, U37.13
3.3V37: C75.1, I2C_PU37.2, J112.2, R151.2, R152.2, TP149.1, U38.2, U38.13
3.3V38: C77.1, I2C_PU38.2, J115.2, R155.2, R156.2, TP153.1, U39.2, U39.13
3.3V39: C79.1, I2C_PU39.2, J118.2, R159.2, R160.2, TP157.1, U40.2, U40.13
3.3V40: C81.1, I2C_PU40.2, J121.2, R163.2, R164.2, TP161.1, U41.2, U41.13
3.3V41: C83.1, I2C_PU41.2, J124.2, R167.2, R168.2, TP165.1, U42.2, U42.13
3.3V42: C85.1, I2C_PU42.2, J127.2, R171.2, R172.2, TP169.1, U43.2, U43.13
3.3V43: C87.1, I2C_PU43.2, J130.2, R175.2, R176.2, TP173.1, U44.2, U44.13
3.3V44: C89.1, I2C_PU44.2, J133.2, R179.2, R180.2, TP177.1, U45.2, U45.13
3.3V45: C91.1, I2C_PU45.2, J136.2, R183.2, R184.2, TP181.1, U46.2, U46.13
3.3V46: C93.1, I2C_PU46.2, J139.2, R187.2, R188.2, TP185.1, U47.2, U47.13
3.3V47: C95.1, I2C_PU47.2, J142.2, R191.2, R192.2, TP189.1, U48.2, U48.13
3.3V48: C97.1, I2C_PU48.2, J145.2, R195.2, R196.2, TP193.1, U49.2, U49.13
3.3V49: C99.1, I2C_PU49.2, J148.2, R199.2, R200.2, TP197.1, U50.2, U50.13
3.3V50: C101.1, I2C_PU50.2, J151.2, R203.2, R204.2, TP201.1, U51.2, U51.13
3.3V51: C103.1, I2C_PU51.2, J154.2, R207.2, R208.2, TP205.1, U52.2, U52.13
3.3V52: C105.1, I2C_PU52.2, J157.2, R211.2, R212.2, TP209.1, U53.2, U53.13
3.3V53: C107.1, I2C_PU53.2, J160.2, R215.2, R216.2, TP213.1, U54.2, U54.13
3.3V54: C109.1, I2C_PU54.2, J163.2, R219.2, R220.2, TP217.1, U55.2, U55.13
3.3V55: C111.1, I2C_PU55.2, J166.2, R223.2, R224.2, TP221.1, U56.2, U56.13
3.3V56: C113.1, I2C_PU56.2, J169.2, R227.2, R228.2, TP225.1, U57.2, U57.13
3.3V57: C115.1, I2C_PU57.2, J172.2, R231.2, R232.2, TP229.1, U58.2, U58.13
3.3V58: C117.1, I2C_PU58.2, J175.2, R235.2, R236.2, TP233.1, U59.2, U59.13
3.3V59: C119.1, I2C_PU59.2, J178.2, R239.2, R240.2, TP237.1, U60.2, U60.13
3.3V60: C121.1, I2C_PU60.2, J181.2, R243.2, R244.2, TP241.1, U61.2, U61.13
3.3V61: C123.1, I2C_PU61.2, J184.2, R247.2, R248.2, TP245.1, U62.2, U62.13
3.3V62: C125.1, I2C_PU62.2, J187.2, R251.2, R252.2, TP249.1, U63.2, U63.13
3.3V63: C127.1, I2C_PU63.2, J190.2, R255.2, R256.2, TP253.1, U64.2, U64.13
!MAG_CS!: R7.1, U2.4
!MAG_CS!1: R8.1, U1.4
!MAG_CS!2: R12.1, U3.4
!MAG_CS!3: R16.1, U4.4
!MAG_CS!4: R20.1, U5.4
!MAG_CS!5: R24.1, U6.4
!MAG_CS!6: R28.1, U7.4
!MAG_CS!7: R32.1, U8.4
!MAG_CS!8: R36.1, U9.4
!MAG_CS!9: R40.1, U10.4
!MAG_CS!10: R44.1, U11.4
!MAG_CS!11: R48.1, U12.4
!MAG_CS!12: R52.1, U13.4
!MAG_CS!13: R56.1, U14.4
!MAG_CS!14: R60.1, U15.4
!MAG_CS!15: R64.1, U16.4
!MAG_CS!16: R68.1, U17.4
!MAG_CS!17: R72.1, U18.4
!MAG_CS!18: R76.1, U19.4
!MAG_CS!19: R80.1, U20.4
!MAG_CS!20: R84.1, U21.4
!MAG_CS!21: R88.1, U22.4
!MAG_CS!22: R92.1, U23.4
!MAG_CS!23: R96.1, U24.4
!MAG_CS!24: R100.1, U25.4
!MAG_CS!25: R104.1, U26.4
!MAG_CS!26: R108.1, U27.4
!MAG_CS!27: R112.1, U28.4
!MAG_CS!28: R116.1, U29.4
!MAG_CS!29: R120.1, U30.4
!MAG_CS!30: R124.1, U31.4
!MAG_CS!31: R128.1, U32.4
!MAG_CS!32: R132.1, U33.4
!MAG_CS!33: R136.1, U34.4
!MAG_CS!34: R140.1, U35.4
!MAG_CS!35: R144.1, U36.4
!MAG_CS!36: R148.1, U37.4
!MAG_CS!37: R152.1, U38.4
!MAG_CS!38: R156.1, U39.4
!MAG_CS!39: R160.1, U40.4
!MAG_CS!40: R164.1, U41.4
!MAG_CS!41: R168.1, U42.4
!MAG_CS!42: R172.1, U43.4
!MAG_CS!43: R176.1, U44.4
!MAG_CS!44: R180.1, U45.4
!MAG_CS!45: R184.1, U46.4
!MAG_CS!46: R188.1, U47.4
!MAG_CS!47: R192.1, U48.4
!MAG_CS!48: R196.1, U49.4
!MAG_CS!49: R200.1, U50.4
!MAG_CS!50: R204.1, U51.4
!MAG_CS!51: R208.1, U52.4
!MAG_CS!52: R212.1, U53.4
!MAG_CS!53: R216.1, U54.4
!MAG_CS!54: R220.1, U55.4
!MAG_CS!55: R224.1, U56.4
!MAG_CS!56: R228.1, U57.4
!MAG_CS!57: R232.1, U58.4
!MAG_CS!58: R236.1, U59.4
!MAG_CS!59: R240.1, U60.4
!MAG_CS!60: R244.1, U61.4
!MAG_CS!61: R248.1, U62.4
!MAG_CS!62: R252.1, U63.4
!MAG_CS!63: R256.1, U64.4
CAP: C5.1, U2.10
CAP1: C3.1, U1.10
CAP2: C6.1, U3.10
CAP3: C8.1, U4.10
CAP4: C10.1, U5.10
CAP5: C12.1, U6.10
CAP6: C14.1, U7.10
CAP7: C16.1, U8.10
CAP8: C18.1, U9.10
CAP9: C20.1, U10.10
CAP10: C22.1, U11.10
CAP11: C24.1, U12.10
CAP12: C26.1, U13.10
CAP13: C28.1, U14.10
CAP14: C30.1, U15.10
CAP15: C32.1, U16.10
CAP16: C34.1, U17.10
CAP17: C36.1, U18.10
CAP18: C38.1, U19.10
CAP19: C40.1, U20.10
CAP20: C42.1, U21.10
CAP21: C44.1, U22.10
CAP22: C46.1, U23.10
CAP23: C48.1, U24.10
CAP24: C50.1, U25.10
CAP25: C52.1, U26.10
CAP26: C54.1, U27.10
CAP27: C56.1, U28.10
CAP28: C58.1, U29.10
CAP29: C60.1, U30.10
CAP30: C62.1, U31.10
CAP31: C64.1, U32.10
CAP32: C66.1, U33.10
CAP33: C68.1, U34.10
CAP34: C70.1, U35.10
CAP35: C72.1, U36.10
CAP36: C74.1, U37.10
CAP37: C76.1, U38.10
CAP38: C78.1, U39.10
CAP39: C80.1, U40.10
CAP40: C82.1, U41.10
CAP41: C84.1, U42.10
CAP42: C86.1, U43.10
CAP43: C88.1, U44.10
CAP44: C90.1, U45.10
CAP45: C92.1, U46.10
CAP46: C94.1, U47.10
CAP47: C96.1, U48.10
CAP48: C98.1, U49.10
CAP49: C100.1, U50.10
CAP50: C102.1, U51.10
CAP51: C104.1, U52.10
CAP52: C106.1, U53.10
CAP53: C108.1, U54.10
CAP54: C110.1, U55.10
CAP55: C112.1, U56.10
CAP56: C114.1, U57.10
CAP57: C116.1, U58.10
CAP58: C118.1, U59.10
CAP59: C120.1, U60.10
CAP60: C122.1, U61.10
CAP61: C124.1, U62.10
CAP62: C126.1, U63.10
CAP63: C128.1, U64.10
GND: C2.2, C5.2, J1.1, J4.1, LED.1, TP5.1, U2.9, U2.11
GND1: C1.2, C3.2, J3.1, J6.1, LED1.1, TP8.1, U1.9, U1.11
GND2: C4.2, C6.2, J7.1, J9.1, LED2.1, TP12.1, U3.9, U3.11
GND3: C7.2, C8.2, J10.1, J12.1, LED3.1, TP16.1, U4.9, U4.11
GND4: C9.2, C10.2, J13.1, J15.1, LED4.1, TP20.1, U5.9, U5.11
GND5: C11.2, C12.2, J16.1, J18.1, LED5.1, TP24.1, U6.9, U6.11
GND6: C13.2, C14.2, J19.1, J21.1, LED6.1, TP28.1, U7.9, U7.11
GND7: C15.2, C16.2, J22.1, J24.1, LED7.1, TP32.1, U8.9, U8.11
GND8: C17.2, C18.2, J25.1, J27.1, LED8.1, TP36.1, U9.9, U9.11
GND9: C19.2, C20.2, J28.1, J30.1, LED9.1, TP40.1, U10.9, U10.11
GND10: C21.2, C22.2, J31.1, J33.1, LED10.1, TP44.1, U11.9, U11.11
GND11: C23.2, C24.2, J34.1, J36.1, LED11.1, TP48.1, U12.9, U12.11
GND12: C25.2, C26.2, J37.1, J39.1, LED12.1, TP52.1, U13.9, U13.11
GND13: C27.2, C28.2, J40.1, J42.1, LED13.1, TP56.1, U14.9, U14.11
GND14: C29.2, C30.2, J43.1, J45.1, LED14.1, TP60.1, U15.9, U15.11
GND15: C31.2, C32.2, J46.1, J48.1, LED15.1, TP64.1, U16.9, U16.11
GND16: C33.2, C34.2, J49.1, J51.1, LED16.1, TP68.1, U17.9, U17.11
GND17: C35.2, C36.2, J52.1, J54.1, LED17.1, TP72.1, U18.9, U18.11
GND18: C37.2, C38.2, J55.1, J57.1, LED18.1, TP76.1, U19.9, U19.11
GND19: C39.2, C40.2, J58.1, J60.1, LED19.1, TP80.1, U20.9, U20.11
GND20: C41.2, C42.2, J61.1, J63.1, LED20.1, TP84.1, U21.9, U21.11
GND21: C43.2, C44.2, J64.1, J66.1, LED21.1, TP88.1, U22.9, U22.11
GND22: C45.2, C46.2, J67.1, J69.1, LED22.1, TP92.1, U23.9, U23.11
GND23: C47.2, C48.2, J70.1, J72.1, LED23.1, TP96.1, U24.9, U24.11
GND24: C49.2, C50.2, J73.1, J75.1, LED24.1, TP100.1, U25.9, U25.11
GND25: C51.2, C52.2, J76.1, J78.1, LED25.1, TP104.1, U26.9, U26.11
GND26: C53.2, C54.2, J79.1, J81.1, LED26.1, TP108.1, U27.9, U27.11
GND27: C55.2, C56.2, J82.1, J84.1, LED27.1, TP112.1, U28.9, U28.11
GND28: C57.2, C58.2, J85.1, J87.1, LED28.1, TP116.1, U29.9, U29.11
GND29: C59.2, C60.2, J88.1, J90.1, LED29.1, TP120.1, U30.9, U30.11
GND30: C61.2, C62.2, J91.1, J93.1, LED30.1, TP124.1, U31.9, U31.11
GND31: C63.2, C64.2, J94.1, J96.1, LED31.1, TP128.1, U32.9, U32.11
GND32: C65.2, C66.2, J97.1, J99.1, LED32.1, TP132.1, U33.9, U33.11
GND33: C67.2, C68.2, J100.1, J102.1, LED33.1, TP136.1, U34.9, U34.11
GND34: C69.2, C70.2, J103.1, J105.1, LED34.1, TP140.1, U35.9, U35.11
GND35: C71.2, C72.2, J106.1, J108.1, LED35.1, TP144.1, U36.9, U36.11
GND36: C73.2, C74.2, J109.1, J111.1, LED36.1, TP148.1, U37.9, U37.11
GND37: C75.2, C76.2, J112.1, J114.1, LED37.1, TP152.1, U38.9, U38.11
GND38: C77.2, C78.2, J115.1, J117.1, LED38.1, TP156.1, U39.9, U39.11
GND39: C79.2, C80.2, J118.1, J120.1, LED39.1, TP160.1, U40.9, U40.11
GND40: C81.2, C82.2, J121.1, J123.1, LED40.1, TP164.1, U41.9, U41.11
GND41: C83.2, C84.2, J124.1, J126.1, LED41.1, TP168.1, U42.9, U42.11
GND42: C85.2, C86.2, J127.1, J129.1, LED42.1, TP172.1, U43.9, U43.11
GND43: C87.2, C88.2, J130.1, J132.1, LED43.1, TP176.1, U44.9, U44.11
GND44: C89.2, C90.2, J133.1, J135.1, LED44.1, TP180.1, U45.9, U45.11
GND45: C91.2, C92.2, J136.1, J138.1, LED45.1, TP184.1, U46.9, U46.11
GND46: C93.2, C94.2, J139.1, J141.1, LED46.1, TP188.1, U47.9, U47.11
GND47: C95.2, C96.2, J142.1, J144.1, LED47.1, TP192.1, U48.9, U48.11
GND48: C97.2, C98.2, J145.1, J147.1, LED48.1, TP196.1, U49.9, U49.11
GND49: C99.2, C100.2, J148.1, J150.1, LED49.1, TP200.1, U50.9, U50.11
GND50: C101.2, C102.2, J151.1, J153.1, LED50.1, TP204.1, U51.9, U51.11
GND51: C103.2, C104.2, J154.1, J156.1, LED51.1, TP208.1, U52.9, U52.11
GND52: C105.2, C106.2, J157.1, J159.1, LED52.1, TP212.1, U53.9, U53.11
GND53: C107.2, C108.2, J160.1, J162.1, LED53.1, TP216.1, U54.9, U54.11
GND54: C109.2, C110.2, J163.1, J165.1, LED54.1, TP220.1, U55.9, U55.11
GND55: C111.2, C112.2, J166.1, J168.1, LED55.1, TP224.1, U56.9, U56.11
GND56: C113.2, C114.2, J169.1, J171.1, LED56.1, TP228.1, U57.9, U57.11
GND57: C115.2, C116.2, J172.1, J174.1, LED57.1, TP232.1, U58.9, U58.11
GND58: C117.2, C118.2, J175.1, J177.1, LED58.1, TP236.1, U59.9, U59.11
GND59: C119.2, C120.2, J178.1, J180.1, LED59.1, TP240.1, U60.9, U60.11
GND60: C121.2, C122.2, J181.1, J183.1, LED60.1, TP244.1, U61.9, U61.11
GND61: C123.2, C124.2, J184.1, J186.1, LED61.1, TP248.1, U62.9, U62.11
GND62: C125.2, C126.2, J187.1, J189.1, LED62.1, TP252.1, U63.9, U63.11
GND63: C127.2, C128.2, J190.1, J192.1, LED63.1, TP256.1, U64.9, U64.11
INT: J2.1, U2.15
INT1: J5.1, U1.15
INT2: J8.1, U3.15
INT3: J11.1, U4.15
INT4: J14.1, U5.15
INT5: J17.1, U6.15
INT6: J20.1, U7.15
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

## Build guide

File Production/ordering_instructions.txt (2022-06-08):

panel size, 79x170mm
PCB thickness, 1.6mm
number of layers, 2
soldermask color, Red
silkscreen color, White
oz copper, 1oz
finish, HASL lead free
stencils, top
pcs per panel, 64
min trace width, 0.1270mm / 0.0050in
min drill size, 0.3048mm / 0.0120in

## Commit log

2022-04-28 Places parts, fixes some schematic alignment issues
    [SparkFun_Magnetometer_MMC5983MA_Qwiic_Micro.brd, SparkFun_Magnetometer_MMC5983MA_Qwiic_Micro.sch]
2022-04-28 Adds measures
    [SparkFun_Magnetometer_MMC5983MA_Qwiic_Micro.brd]
2022-04-28 Routes the board
    [SparkFun_Magnetometer_MMC5983MA_Qwiic_Micro.brd, SparkFun_Magnetometer_MMC5983MA_Qwiic_Micro.sch]
2022-04-29 Adds Silk, moves testpoints to grid, updates two pin connector
    [SparkFun_Magnetometer_MMC5983MA_Qwiic_Micro.brd, SparkFun_Magnetometer_MMC5983MA_Qwiic_Micro.sch]
2022-05-02 Moves interrupt and ground pins, fixes silk, moves testpoints to 0.0375" grid
    [SparkFun_Magnetometer_MMC5983MA_Qwiic_Micro.brd, SparkFun_Magnetometer_MMC5983MA_Qwiic_Micro.sch]
2022-05-02 Adds measures, adds 0402 RED LED from lib
    [SparkFun_Magnetometer_MMC5983MA_Qwiic_Micro.brd, SparkFun_Magnetometer_MMC5983MA_Qwiic_Micro.sch]
2022-05-31 Increases the size of the silk, fixes measures, rolls to version v10
    [SparkFun_Magnetometer_MMC5983MA_Qwiic_Micro.brd, SparkFun_Magnetometer_MMC5983MA_Qwiic_Micro.sch]
2022-06-02 Updates magnetometer symbol, moves I2C silk
    [SparkFun_Magnetometer_MMC5983MA_Qwiic_Micro.brd, SparkFun_Magnetometer_MMC5983MA_Qwiic_Micro.sch]
2022-06-08 Adds Production Files
    [SparkFun_Magnetometer_MMC5983MA_Qwiic_Micro-Panel.brd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]

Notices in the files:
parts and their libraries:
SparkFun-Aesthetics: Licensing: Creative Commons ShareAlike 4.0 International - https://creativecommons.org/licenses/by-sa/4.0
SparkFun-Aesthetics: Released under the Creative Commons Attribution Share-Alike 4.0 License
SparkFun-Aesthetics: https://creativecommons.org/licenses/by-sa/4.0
